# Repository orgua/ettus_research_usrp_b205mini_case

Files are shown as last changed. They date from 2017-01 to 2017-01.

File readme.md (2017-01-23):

3D printable Enclosure for the Ettus Research USRP B200mini and [B205mini](https://www.ettus.com/product/details/USRP-B205mini-i)
===================================================================

This case is smaller and cheaper than the original case from Ettus. And you can modify it to show a logo or add other features. It was tested with an alumide-print from Shapeways and is now used for two USRPs.

URSP B200

## tested print from Shapeways
- polished [metal plastic](https://www.shapeways.com/materials/metallic-plastic?li=nav) (alumide)
- case top cost ~35€
- case bottom costs ~31€
- Result: very accurate print, included tolerances not fully needed

## extra parts for assembly
- 4x M3 12mm cylinder Screws (hexagon socket)
- 4x M3 Nuts (self-locking)
- 3x 3mm [light pipes](https://www.conrad.de/de/lichtleiter-zur-frontplatten-montage-mentor-12822000-planar-183506.html)
- Thermal Pads 1mm thick (Double Adhesive Heat Transfer Pads) for FPGA and ADC
- conductive copper foil tape to shield the cages (optional)
   
## Pictures

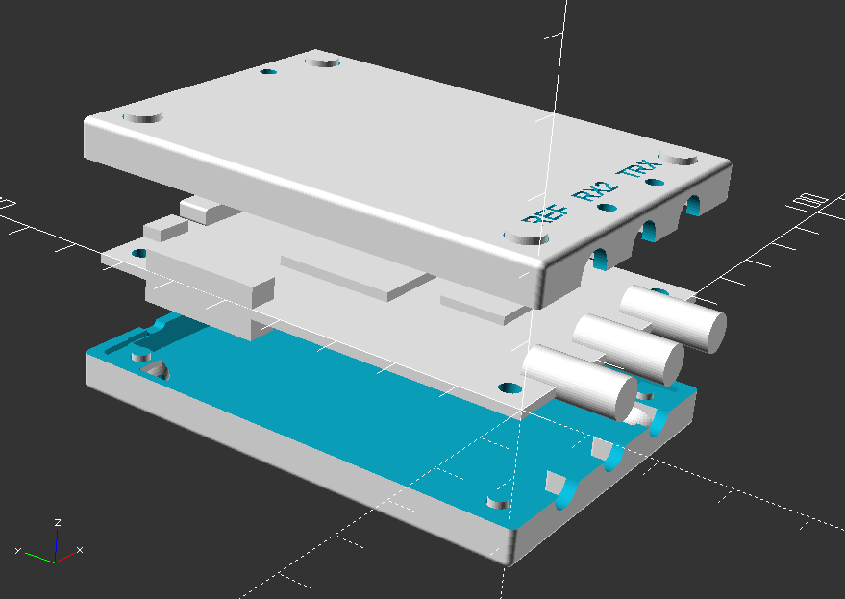
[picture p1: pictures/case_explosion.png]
case explosion
  

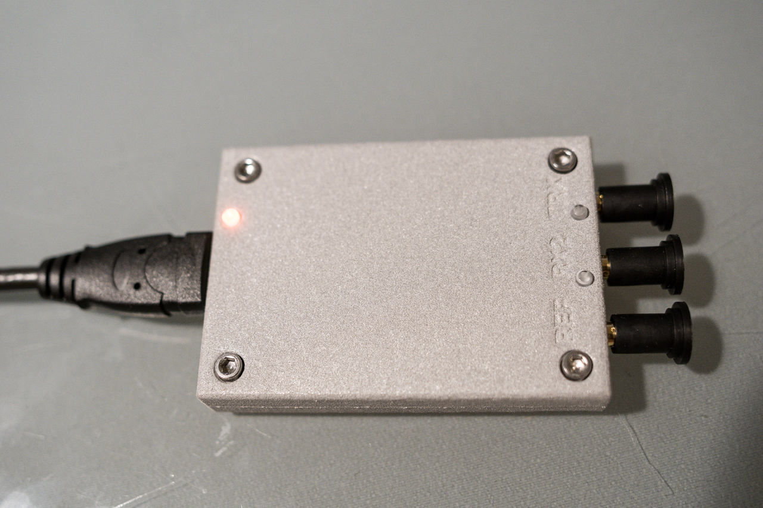
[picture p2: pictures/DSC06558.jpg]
case assembled C


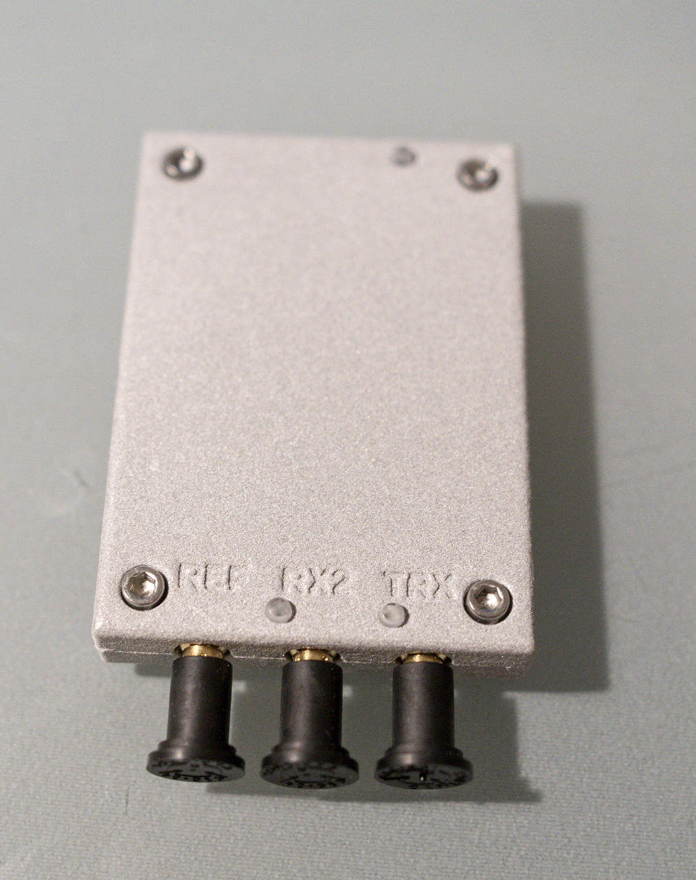
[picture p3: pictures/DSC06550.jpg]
case assembled A

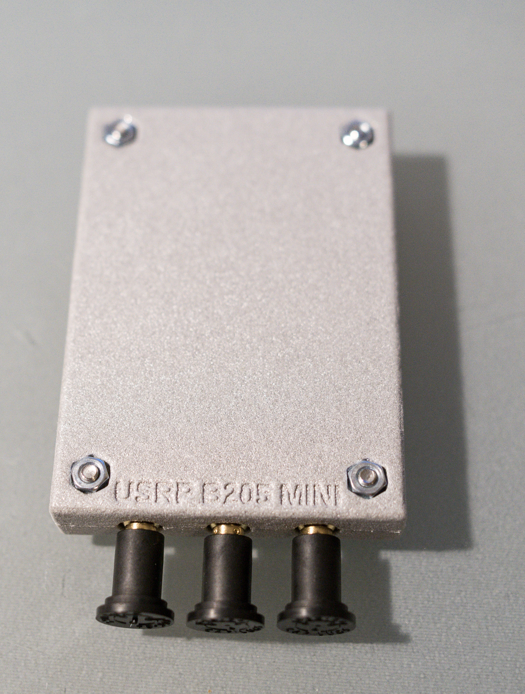
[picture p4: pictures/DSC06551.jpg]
case assembled B


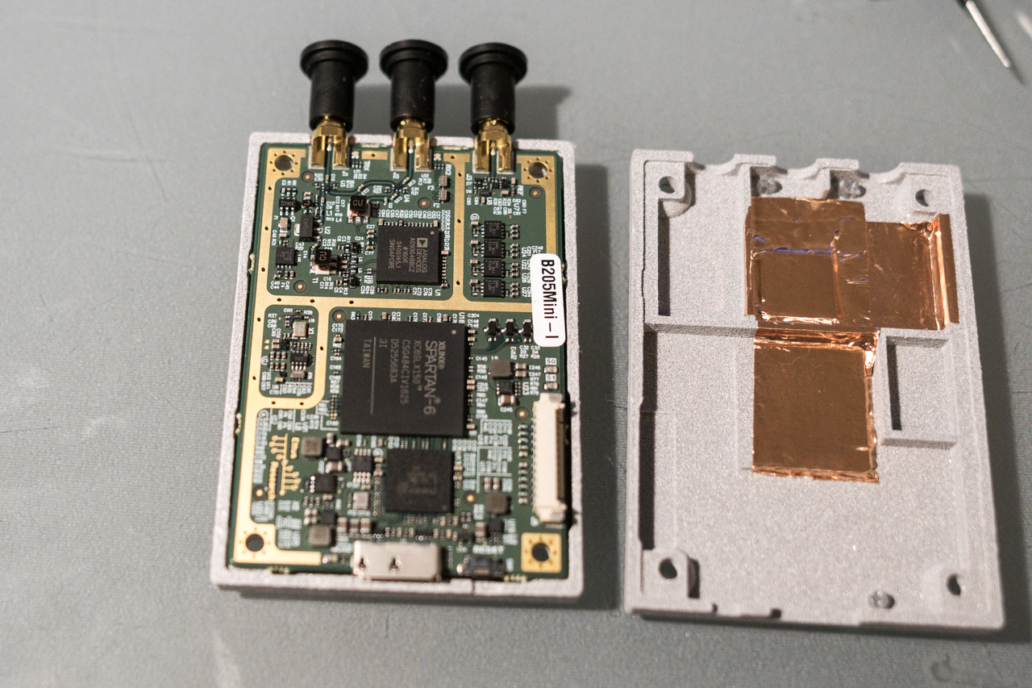
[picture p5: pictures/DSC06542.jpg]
case inside A

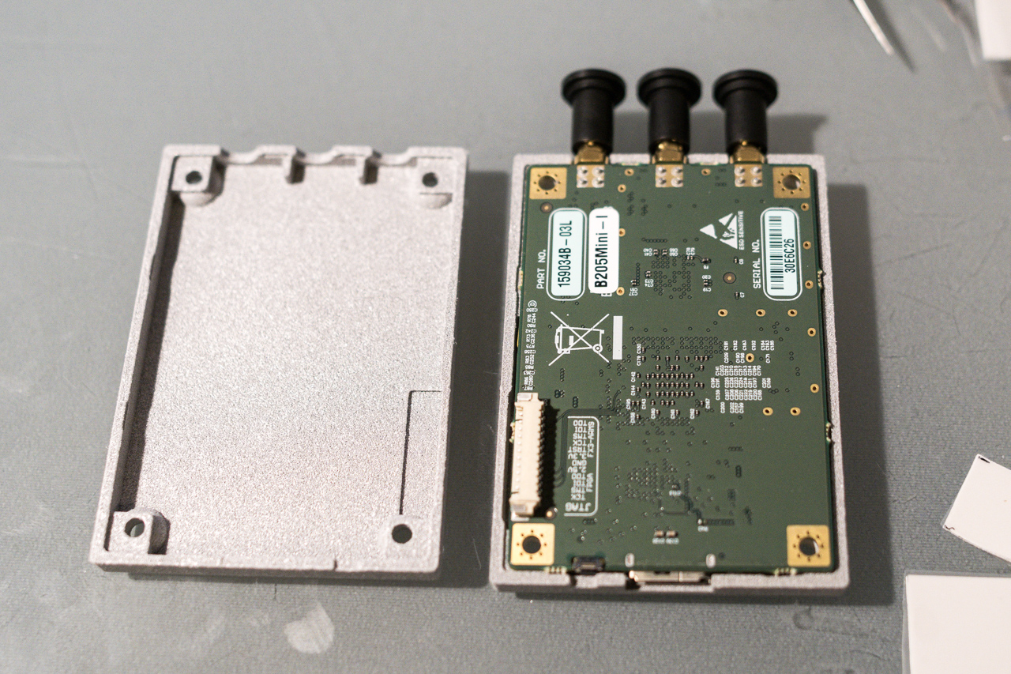
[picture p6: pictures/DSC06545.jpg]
case inside B


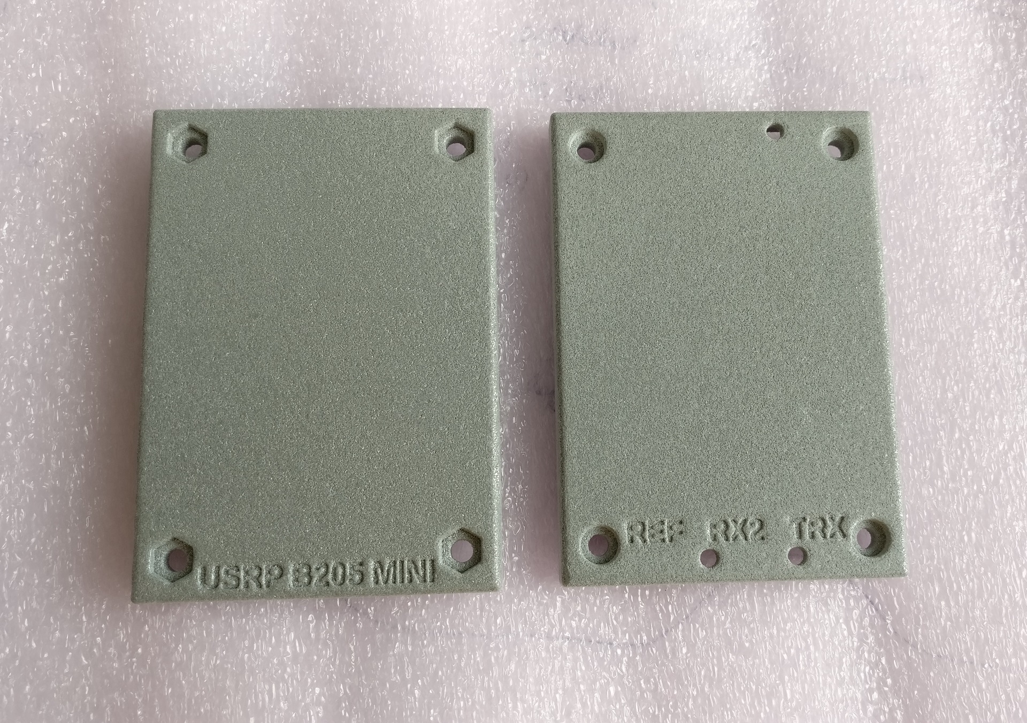
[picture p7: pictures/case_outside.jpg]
case outside


## todo
- update link [thingiverse](http://www.thingiverse.com/thing:1892671)
- possible changes
   - reset hole could go 0.5mm to usb-port

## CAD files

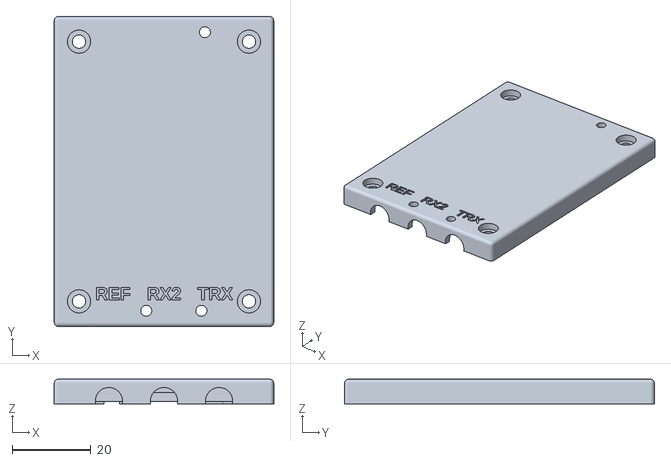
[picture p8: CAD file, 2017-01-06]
result/B200mini_case_top.stl
55.8 x 78.8 x 6.25

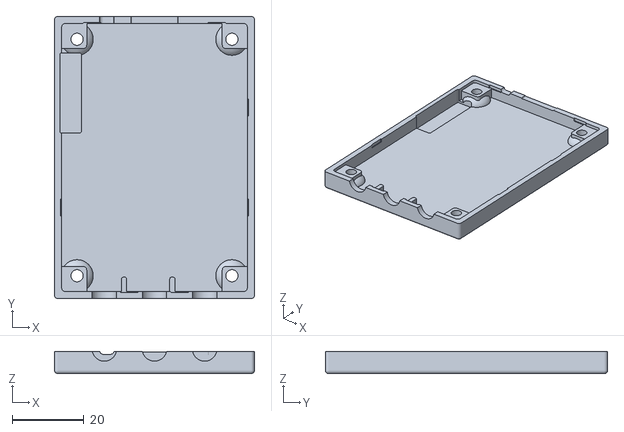
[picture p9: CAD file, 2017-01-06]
result/B200mini_case_bot.stl
55.8 x 78.8 x 6.25

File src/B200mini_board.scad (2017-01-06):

//
// B200mini Case Model
// 

// center: upper left corner on top of the PCB

include <misc_parts.scad>;

$fn = 48;

// PCB of the usrp
pcbWid = 50.8 + 1; // mm + safetymargin / clearance
pcbLen = 73.8 + 1; // mm
pcbHgt = 1.6 + 0.0; // mm
pcbX = +pcbWid / 2;
pcbY = +pcbLen / 2;
pcbZ = -pcbHgt / 2;

// SMA connectors
smaDia = 6.3; // mm
smaLen = 14.5; // mm
smaInset = 5.5; // mm
smaX1 = pcbX - 14; 
smaX2 = pcbX;
smaX3 = pcbX + 14;
smaY  = smaInset - smaLen / 2;
smaZ  = 0.1;

// header, both evaluated together
hdrLen = 20.4; // mm
hdrWid = 5; // mm
hdrHgt = 8.5; // mm, datasheet
hdrInset = 5.2; // mm
hdrX = hdrWid/2;
hdrY = 65.6 - hdrLen/2;
hdrZ = pcbZ;

// usb connector
usbWid = 13; // mm
usbLen = 5.6; // mm
usbHgt = 2.9; // mm
usbInset = 4.0; // mm
usbX = pcbX;
usbY = pcbLen - usbInset + usbLen/2;
usbZ = usbHgt / 2 - 0.1;

// screw - holes for assembly
holeDia = 3.2; // mm
holeX1  = pcbX - 43.2/2;
holeX2  = pcbX + 43.2/2;
holeY1  = pcbY - 66.0/2;
holeY2  = pcbY + 66.0/2;

// reset component
rstWid = 6.5; // mm
rstLen = 3.5; // mm
rstHgt = 4.3; // mm
rstX    = 12.6;
rstY    = pcbLen - rstLen/2;
rstZ    = -0.2;

// Reset - Button itself
rstBWid = 4.0; 
rstBHgt = 2.5;

// milling tabs, case should offer a little space for it
mtbLen = 5.0;
mtbWid = 0.6;
mtbX1A = 0;
mtbX1B = pcbWid;
mtbY1A = pcbY - 14;
mtbY1B = pcbY + 14;

mtbX2A = pcbX - 17.4;
mtbX2B = pcbX + 17.4;
mtbY2  = pcbLen;

mtbX3A = pcbX - 7;
mtbX3B = pcbX + 7;
mtbY3  = 0;

// ICs - for cooling with heatPad and metalCase
heatPadHgt = 0.8;

fpgaHgt = 1.6;
fpgaWid = 19+1;
fpgaX   = (35+16)/2; // upper border to beginning and ending of IC
fpgaY   = (52 + 33)/2;

adcHgt  = 1.4;
adcWid  = 10+1;
adcX    = (31 + 21) /2; 
adcY    = (16 + 26)/2;


module B200mini() {
  
  difference() {
    union() {
      // PCB 
      translate([pcbX,pcbY,pcbZ])  cube([pcbWid,pcbLen,pcbHgt], center=true);
        
      // SMA-Connectors
      translate([smaX1,smaY,smaZ]) rotate([90,0,0]) cylinder(d=smaDia,h=smaLen,center=true);
      translate([smaX2,smaY,smaZ]) rotate([90,0,0]) cylinder(d=smaDia,h=smaLen,center=true);
      translate([smaX3,smaY,smaZ]) rotate([90,0,0]) cylinder(d=smaDia,h=smaLen,center=true);
      
      // Header
      translate([hdrX,hdrY,hdrZ])  cube([hdrWid,hdrLen,hdrHgt],center=true);
      
      // USB3 Connector  
      translate([usbX,usbY,usbZ])  rotate([90,0,0]) round_cuboid(usbWid,usbHgt,usbLen,0.5);
      
      // reset-button
      translate([rstX,rstY,rstZ])  cube([rstWid, rstLen, rstHgt], center=true);
      
        
      // ICs
      translate([fpgaX,fpgaY,fpgaHgt/2])  cube([fpgaWid,fpgaWid,fpgaHgt],center=true);
      translate([adcX,adcY,adcHgt/2])     cube([adcWid,adcWid,adcHgt],center=true);  
    }
    
    // Mounting-Holes
    translate([holeX1,holeY1,0]) cylinder(d=holeDia,h=10,center=true);
    translate([holeX1,holeY2,0]) cylinder(d=holeDia,h=10,center=true);
    translate([holeX2,holeY1,0]) cylinder(d=holeDia,h=10,center=true);
    translate([holeX2,holeY2,0]) cylinder(d=holeDia,h=10,center=true);
  }
}

// its a mockup with a little bit more clearance for substracting it from the case
module B200mini_neg() 
{
    // PCB 
    translate([pcbX,pcbY,pcbZ])  round_cuboid(pcbWid,pcbLen,pcbHgt,1);
       
    // SMA-Connectors
    translate([smaX1,smaY,smaZ]) rotate([90,0,0]) cylinder(d=smaDia+0.6,h=smaLen,center=true);
    translate([smaX2,smaY,smaZ]) rotate([90,0,0]) cylinder(d=smaDia+0.6,h=smaLen,center=true);
    translate([smaX3,smaY,smaZ]) rotate([90,0,0]) cylinder(d=smaDia+0.6,h=smaLen,center=true);
    
    // Header
    translate([hdrX,hdrY,hdrZ])  round_cuboid(hdrWid+1,hdrLen+2,hdrHgt+1.0,0.5);
    
    // USB3 Connector  
    translate([usbX,usbY,usbZ-0.4])  rotate([90,0,0]) round_cuboid(usbWid+0.3,usbHgt+0.6,usbLen+3,0.4);
    
    // reset-component
    translate([rstX,rstY,rstZ])  cube([rstWid, rstLen, rstHgt], center=true);

    // Reset cutout
    translate([rstX,rstY,rstZ]) rotate([90,0,0]) round_cuboid(rstBWid,rstBHgt,10,1);   

    // milling tabs
    translate([mtbX1A,mtbY1A,pcbZ]) round_cuboid(mtbWid,mtbLen,pcbHgt,mtbWid/2); 
    translate([mtbX1A,mtbY1B,pcbZ]) round_cuboid(mtbWid,mtbLen,pcbHgt,mtbWid/2); 
    translate([mtbX1B,mtbY1A,pcbZ]) round_cuboid(mtbWid,mtbLen,pcbHgt,mtbWid/2); 
    translate([mtbX1B,mtbY1B,pcbZ]) round_cuboid(mtbWid,mtbLen,pcbHgt,mtbWid/2); 

    translate([mtbX2A,mtbY2 ,pcbZ]) round_cuboid(mtbLen,mtbWid,pcbHgt,mtbWid/2); 
    translate([mtbX2B,mtbY2 ,pcbZ]) round_cuboid(mtbLen,mtbWid,pcbHgt,mtbWid/2); 
    translate([mtbX3A,mtbY3 ,pcbZ]) round_cuboid(mtbLen,mtbWid,pcbHgt,mtbWid/2); 
    translate([mtbX3B,mtbY3 ,pcbZ]) round_cuboid(mtbLen,mtbWid,pcbHgt,mtbWid/2); 
        
    // ICs
    translate([fpgaX,fpgaY,(fpgaHgt+heatPadHgt)/2])  cube([fpgaWid+1.5,fpgaWid+1.5,fpgaHgt+heatPadHgt+0.1],center=true);
    translate([adcX,adcY,(adcHgt+heatPadHgt)/2])     cube([adcWid+1.5,adcWid+1.5,adcHgt+heatPadHgt+0.1],center=true);  
    
    // Mounting-Holes
    translate([holeX1,holeY1,0]) cylinder(d=holeDia+0.2,h=20,center=true);
    translate([holeX1,holeY2,0]) cylinder(d=holeDia+0.2,h=20,center=true);
    translate([holeX2,holeY1,0]) cylinder(d=holeDia+0.2,h=20,center=true);
    translate([holeX2,holeY2,0]) cylinder(d=holeDia+0.2,h=20,center=true);
}

//B200mini_neg();
//B200mini();

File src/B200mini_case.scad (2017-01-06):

include <B200mini_board.scad>;
include <misc_parts.scad>;

// Latest Changes: 
// - make screw larger, real size -> measured 
// - 3mm lightpipeCheck -> 2.8 
// - header height not right -> fixed 
// - sink pcb half in both case-parts? Yes
// - thin support for bridge between sma
// - 2x2 Lightpipes next to SMA and header -> nur SMA 
// - header-position seems to be off -> fixed und hole closed
// - outer line of cage added, thicker material
// - usb hole is badly positioned
// - offer a bit more material around the cutout

// TODO: 
// - add logo, USRP on Top?
// - make case asymmetrical? usb hole could be closed from below

// visualisation - config
explosion_distance = 16; // mm, for explosion-view
cutAtY = 1000; // ie. adcY, hdrY, fpgaY
renderTop  = 1;
renderBot  = 0;
renderUSRP = 0;
renderScrw = 0;
hqMode = 1;

if (hqMode) 
{
    $fn = 60;
}

// case main body
WallThi = 2.0;
caseLen = pcbLen+2*WallThi;
caseWid = pcbWid+2*WallThi;
caseHgt = 12.5;
caseX = pcbX;
caseY = pcbY;
caseZ = smaZ-0.7; // starting point

// inner body-holy
iHoleHgt = caseHgt - 2*WallThi;

// separation Cages 
csThi = 1.5; 
csHgt = iHoleHgt / 2 + 0.5;
csZ1 = caseZ + csHgt/2;
csZ2 = caseZ - csHgt/2;

csAWid = pcbWid+2; // biggest separation line from top to bottom
csAX = pcbX;
csAY = 29.5;

csBLen = csAY+1; // line between SMA
csBX = pcbX - 8.5;
csBY = csAY/2-0.5;

csCWid = 12.0 + csThi;    // Line Next to fpga
csCX   = pcbWid-csCWid/2+0.1;
csCY   = 47;

csDLen = 17.5 + csThi; // Line Next to fpga
csDX   = pcbWid - csCWid;
csDY   = (csAY + csCY) / 2;

// extra support for the Short Standoffs between the SMA-Connectors
csSLen = 5; 
csSX1 = csBX;
csSX2 = pcbX + 5.0;
csSY  = csSLen/2-1;

// screw-definition
screwLen = 10;

M3_screw_dia = 3.0; // mm, 2.9 measured
M3_head_dia   = 5.5;
M3_head_Hgt = 3.0;
M3_nut_dia   = 5.5;
M3_nut_Hgt = 2;

screwZ = caseZ - caseHgt/2 + M3_nut_Hgt - 0.5;

// screw Standoffs on top and bottom
ssoR   = 1;
ssoWid = 7.0 + ssoR; // == Len
ssoHgt = caseHgt - 1;

ssoX1 = 0 + ssoWid/2 - ssoR;
ssoX2 = pcbWid - ssoWid/2 + ssoR;
ssoY1 = 0 + ssoWid/2 - ssoR;
ssoY2 = pcbLen - ssoWid/2 + ssoR;


// screw hole fixture -> offer a bit more material around the cutout for screwhead and nut because the main standoffs must be small for not damaging components on the board
shfDia = 9.0;
shfHgt = 3.0;
shfZ1 = caseZ + caseHgt/2 - WallThi - shfHgt/2 + 0.2;
shfZ2 = caseZ - caseHgt/2 + WallThi + shfHgt/2 - 0.2;

// LED- hole for the lightpipe, 
// https://www.conrad.de/de/lichtleiter-zur-frontplatten-montage-mentor-12822000-planar-183506.html
ledDia = 2.8; 
ledX1 = pcbWid - 15.5;
ledY1 = pcbLen - 2;
ledZ = caseZ + caseHgt/2;

ledX2A = pcbX - 4.5;
ledX2B = pcbX + 9.5;
ledY2  = 2;


// text
textFont = "Liberation Sans:style=Bold"; 
textX1 = smaX1+1;
textX2 = smaX2;
textX3 = smaX3-1;
textY  = 4.7;
textZ1  = caseZ + caseHgt/2;
textZ2  = caseZ - caseHgt/2;


module textline(textline)
{
    translate([0,0,-0.5]) 
        rotate([0,0,00]) 
            linear_extrude(height = 1) 
                text(textline, font = textFont, size = 3.3, direction = "ltr", spacing = 1, halign = "center");
}

module screw_M3(length) 
{
    rotate([0,0,30]) translate([0,0,-M3_nut_Hgt/2])
    {
    translate([0,0,length+M3_head_Hgt/2]) cylinder(d=M3_head_dia, h=M3_head_Hgt, center=true);
    cylinder(d=M3_screw_dia, h=length+0.1);
    cylinder(d=M3_nut_dia*1/cos(180/6), h=M3_nut_Hgt, center=true, $fn=6);
    }
}

module screw_M3_neg(length) 
{
    mgn = 0.4;
    rotate([0,0,30]) translate([0,0,-M3_nut_Hgt/2])
    {
    translate([0,0,length+M3_head_Hgt/2]) cylinder(d=M3_head_dia+mgn, h=M3_head_Hgt, center=true);
    cylinder(d=M3_screw_dia+mgn, h=length+0.1);
    cylinder(d=M3_nut_dia*1/cos(180/6)+mgn, h=M3_nut_Hgt+mgn, center=true, $fn=6);
    }
}

module halfDome(dia, hgt)
{
    translate([0,0,-shfHgt/2]) 
      scale([shfDia,shfDia,2*shfHgt]) 
        difference()
    {
        sphere(d=1,center=true);
        translate([0,0,-1]) cube([2,2,2],center=true);
    }
}


module usrp_case()
{
    difference()
    {
        union() 
        {
            if (hqMode) 
            {
                translate([caseX,caseY,caseZ]) difference() 
                {
                    round_cuboid3(caseWid,caseLen,caseHgt,1);  // case HQ
                    round_cuboid(pcbWid,pcbLen,iHoleHgt,1);  // inner cutout
                }
            }
            else        
            {
                translate([caseX,caseY,caseZ]) difference() 
                {
                    cube([caseWid,caseLen,caseHgt],center=true);  // Case fast version
                    cube([pcbWid,pcbLen,iHoleHgt],center=true);  // inner cutout     
                }
            }
     
            // screw standoffs, both sides
            if (hqMode)
            {
                translate([ssoX1,ssoY1,caseZ]) round_cuboid(ssoWid,ssoWid,ssoHgt,ssoR);
                translate([ssoX2,ssoY1,caseZ]) round_cuboid(ssoWid,ssoWid,ssoHgt,ssoR);
                translate([ssoX1,ssoY2,caseZ]) round_cuboid(ssoWid,ssoWid,ssoHgt,ssoR);
                translate([ssoX2,ssoY2,caseZ]) round_cuboid(ssoWid,ssoWid,ssoHgt,ssoR);
            }
            else
            {
                translate([ssoX1,ssoY1,caseZ]) cube([ssoWid,ssoWid,ssoHgt],center=true);
                translate([ssoX2,ssoY1,caseZ]) cube([ssoWid,ssoWid,ssoHgt],center=true);
                translate([ssoX1,ssoY2,caseZ]) cube([ssoWid,ssoWid,ssoHgt],center=true);
                translate([ssoX2,ssoY2,caseZ]) cube([ssoWid,ssoWid,ssoHgt],center=true);  
            }
            
            // screw hole fixture
            translate([holeX1,holeY1,shfZ1]) rotate([180,0,0]) halfDome(shfDia,shfHgt);
            translate([holeX1,holeY2,shfZ1]) rotate([180,0,0]) halfDome(shfDia,shfHgt);
            translate([holeX2,holeY1,shfZ1]) rotate([180,0,0]) halfDome(shfDia,shfHgt);
            translate([holeX2,holeY2,shfZ1]) rotate([180,0,0]) halfDome(shfDia,shfHgt);
            translate([holeX1,holeY1,shfZ2]) halfDome(shfDia,shfHgt);
            translate([holeX1,holeY2,shfZ2]) halfDome(shfDia,shfHgt);
            translate([holeX2,holeY1,shfZ2]) halfDome(shfDia,shfHgt);
            translate([holeX2,holeY2,shfZ2]) halfDome(shfDia,shfHgt);
   
            // separation lines 1.5mm
            translate([csAX,csAY,csZ1]) cube([csAWid,csThi,csHgt],center=true);
            translate([csBX,csBY,csZ1]) cube([csThi,csBLen,csHgt],center=true);
            translate([csCX,csCY,csZ1]) cube([csCWid,csThi,csHgt],center=true);
            translate([csDX,csDY,csZ1]) round_cuboid(csThi,csDLen,csHgt,0.5);
            
            // cage outline 2.5mm
            csThi2 = 2.5;
            translate([pcbWid-csThi2/2,pcbY,csZ1]) cube([csThi2,pcbLen+1,csHgt],center=true); // long line
            translate([csThi2/2,csBY,csZ1])      cube([csThi2,csBLen+1,csHgt],center=true); // shorter one
            
            // extra support for the Short Standoffs between the SMA-Connectors
            translate([csSX2,csSY,csZ1]) round_cuboid(csThi,csSLen,csHgt,0.5);
            translate([csSX1,csSY,csZ2]) round_cuboid(csThi,csSLen,csHgt,0.5);
            translate([csSX2,csSY,csZ2]) round_cuboid(csThi,csSLen,csHgt,0.5);
            
            // FPGA + ADC Cooling Pads
            if (hqMode)
            {
                translate([fpgaX,fpgaY,csZ1])  round_cuboid(fpgaWid+1,fpgaWid+1,csHgt,1);
                translate([adcX,adcY,csZ1])    round_cuboid(adcWid+1,adcWid+1,csHgt,1);
            }
            else
            {
                translate([fpgaX,fpgaY,csZ1])  cube([fpgaWid+1,fpgaWid+1,csHgt],center=true);
                translate([adcX,adcY,csZ1])    cube([adcWid+1,adcWid+1,csHgt],center=true);
            } 
        }
             
        B200mini_neg(); 
        
        // space for screws and nuts
        translate([holeX1,holeY1,screwZ]) screw_M3_neg(screwLen);
        translate([holeX1,holeY2,screwZ]) screw_M3_neg(screwLen); 
        translate([holeX2,holeY1,screwZ]) screw_M3_neg(screwLen); 
        translate([holeX2,holeY2,screwZ]) screw_M3_neg(screwLen); 
        
        // LED cutout
        translate([ledX1,ledY1,ledZ]) cylinder(d=ledDia,h=5,center=true);

        translate([ledX2A,ledY2,ledZ]) cylinder(d=ledDia,h=5,center=true);
        translate([ledX2B,ledY2,ledZ]) cylinder(d=ledDia,h=5,center=true);
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

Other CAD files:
src/misc_parts.scad
